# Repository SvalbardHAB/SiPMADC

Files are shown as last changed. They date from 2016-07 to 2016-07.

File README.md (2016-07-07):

# Existing SiPM ADC board

This board contains two dual-channel 10 bit 65MSPS MAX1182 ADCs; kindly provided by Maxim as free samples. There is also a MachXO2
CPLD for data processing, interfacing over SPI with a microcontroller. It is designed to obtain more  quantitative 
data from the SiPM and scintillator detector than the previous comparator board; at the expense of only using four of the 16 channels.

The board also contains the SiPM bias supply, consisting of a -34V inverting buck-boost converter and an op-amp to output the exact
voltage. This, along with the midpoint voltage - note this is not how the board is designed; during assembly a wire connecting 
Vmid to one of the DAC channels was added and U1 was not populated - is set by a TI DAC7564 allowing precise closed-case software adjustment.

At present the board has been assembled and tested. Unfortunately one of the ADC channels is not functioning correctly and
needs to be investigated further; this is suspected to be an assembly issue.

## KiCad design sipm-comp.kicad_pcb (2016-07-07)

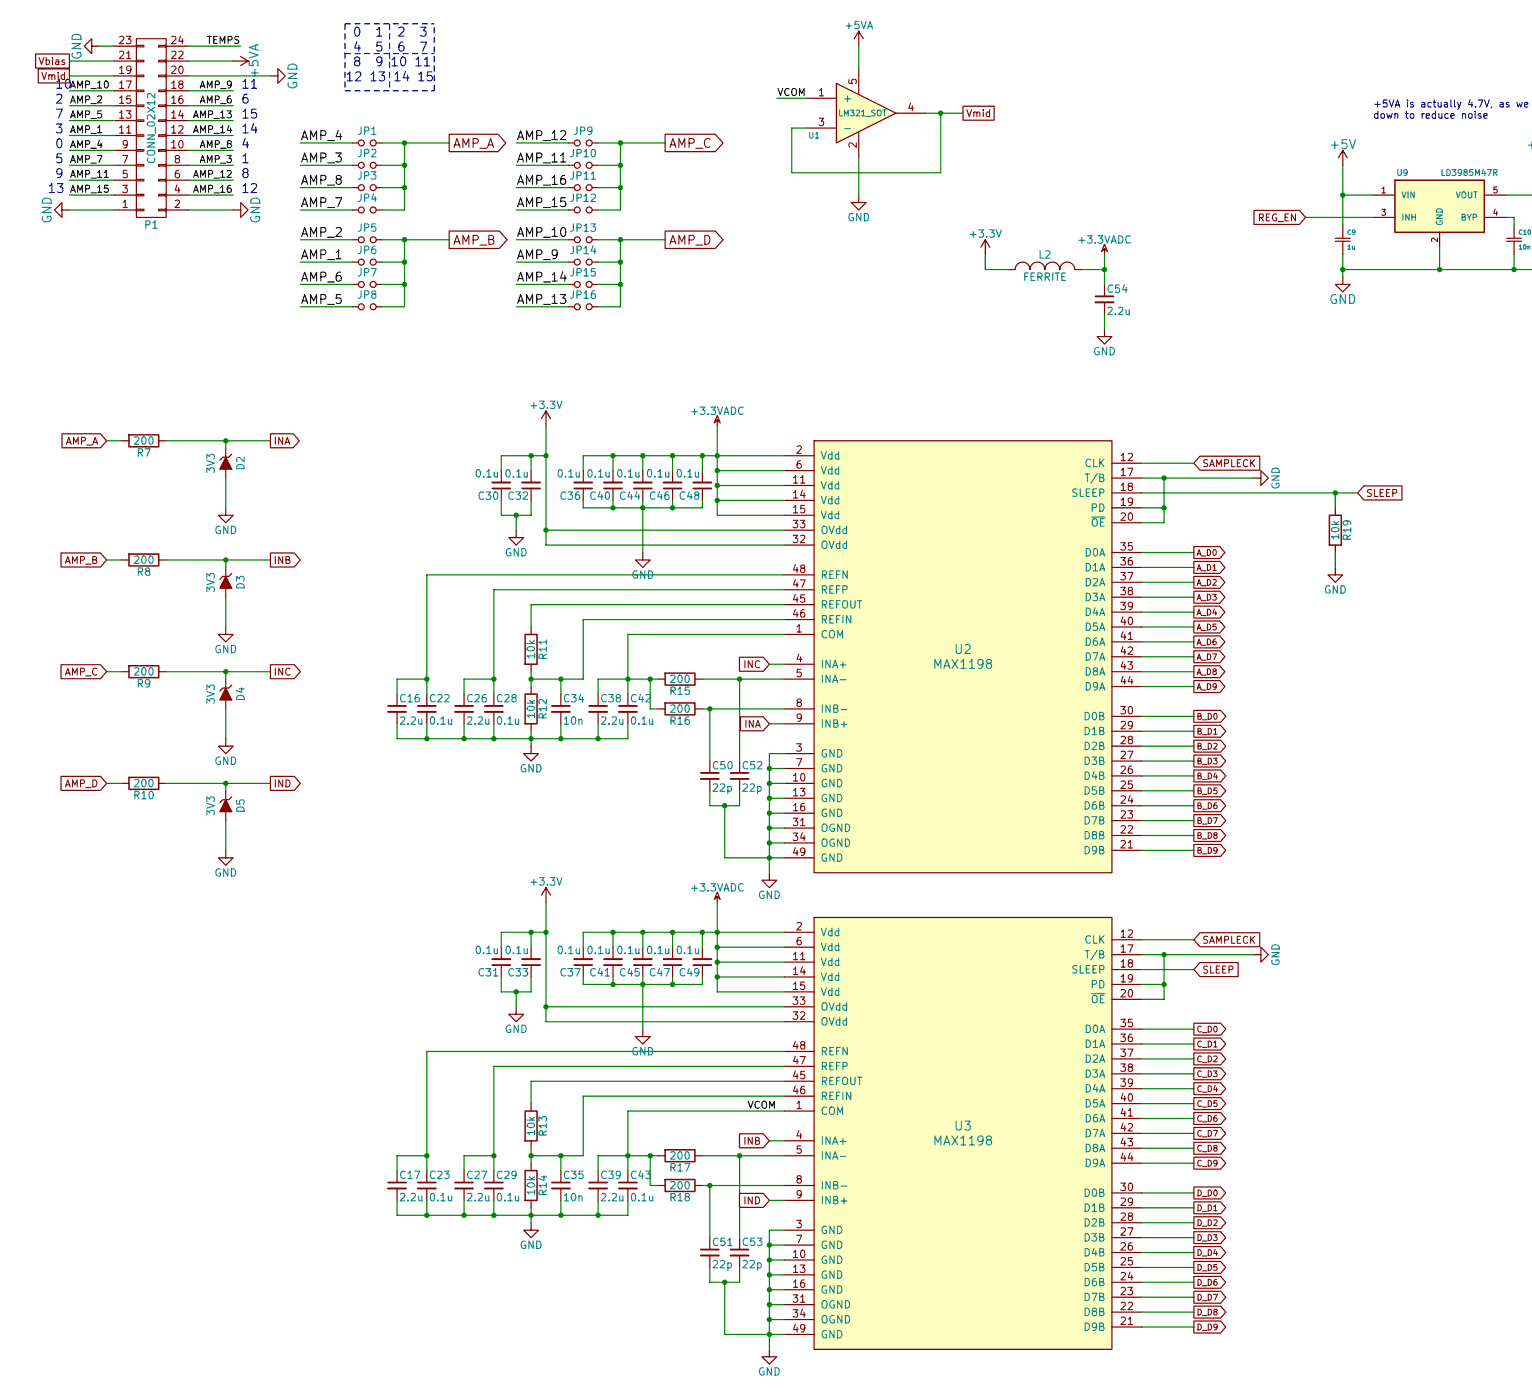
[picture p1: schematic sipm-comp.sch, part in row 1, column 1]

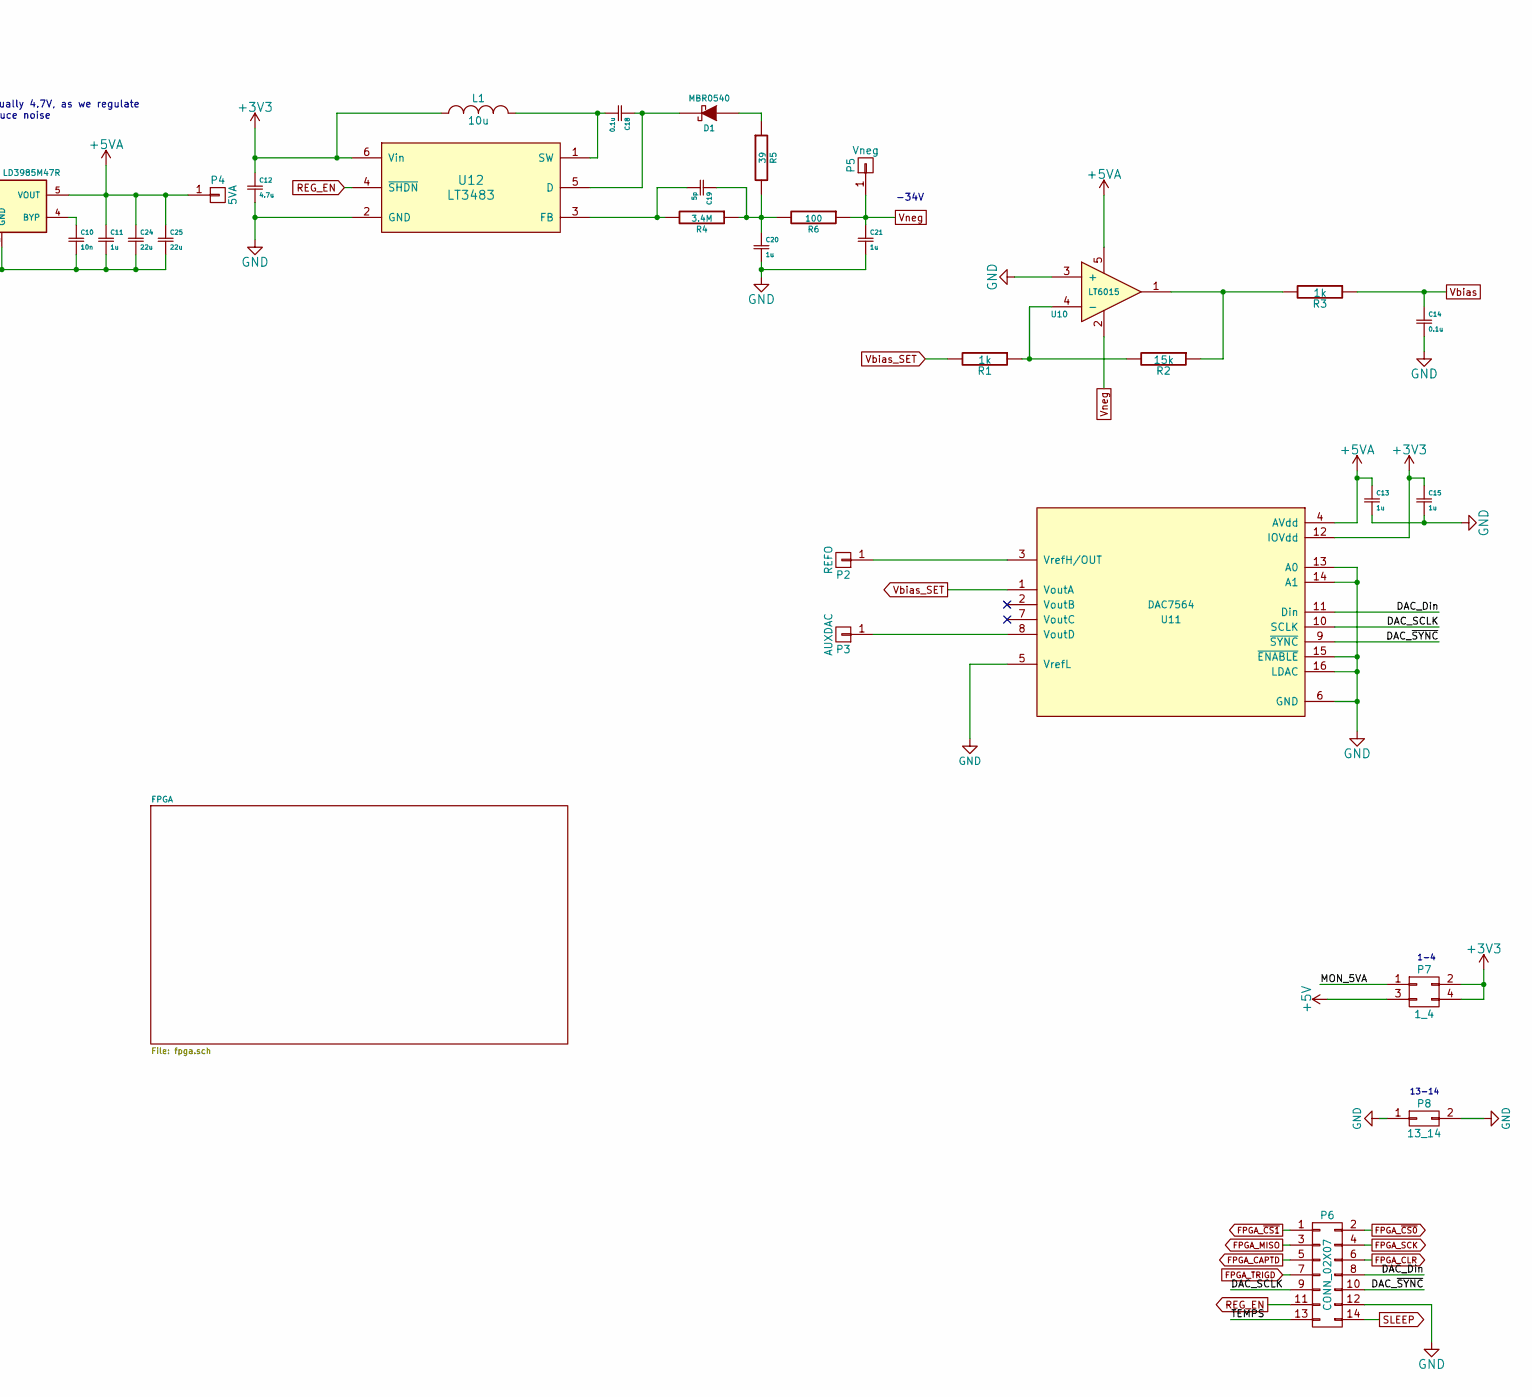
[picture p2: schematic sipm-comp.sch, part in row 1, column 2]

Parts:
C9, C11, C13, C15: 1u; C_0603
C10, C34, C35: 10n; C_0402
C12: 4.7u; C_0805
C14, C18: 0.1u; C_0805
C16, C17, C26, C27, C38, C39, C54: 2.2u; C_0603
C19: 5p; C_0402
C20, C21: 1u; C_1206
C22, C23: 0.1u; C_0603
C24, C25: 22u; C_1206
C28, C29, C30, C31, C32, C33, C36, C37, C40, C41, C42, C43, C44, C45, C46, C47, C48, C49: 0.1u; C_0402
C50, C51, C52, C53: 22p; C_0402
D1: MBR0540; SOD-123
D2, D3, D4, D5: 3V3; SOD-123
JP1, JP2, JP3, JP4, JP5, JP6, JP7, JP8, JP9, JP10, JP11, JP12, JP13, JP14, JP15, JP16: Jumper_NO_Small; MINI_JMPR
L1: 10u; Neosid_Inductor_SM-NE45_SMD1812
L2: FERRITE; R_0805
P1: CONN_02X12; Pin_Header_Angled_2x12
P2: REFO; Measurement_Point_Round-SMD-Pad_Small
P3: AUXDAC; Measurement_Point_Round-SMD-Pad_Small
P4: 5VA; Measurement_Point_Round-SMD-Pad_Small
P5: Vneg; Measurement_Point_Round-SMD-Pad_Small
P6: CONN_02X07; Pin_Header_Straight_2x07
P7: 1_4; Pin_Header_Straight_2x02
P8: 13_14; Pin_Header_Straight_2x01
R1, R3: 1k; R_0402
R2: 15k; R_0402
R4: 3.4M; R_0402
R5: 39; R_0402
R6: 100; R_0402
R7, R8, R9, R10, R15, R16, R17, R18: 200; R_0402
R11, R12, R13, R14, R19: 10k; R_0402
U1: LM321_SOT; SOT-23-5
U2, U3: MAX1198; LQFP-48_7x7mm_EP4x4
U9: LD3985M47R; SOT-23-5
U10: LT6015; SOT-23-5
U11: DAC7564; TSSOP-16_4.4x5mm_Pitch0.65mm
U12: LT3483; SOT-23-6

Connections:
+3.3VADC: C36.2, C37.2, C40.2, C41.2, C44.2, C45.2, C46.2, C47.2, C48.2, C49.2, C54.1, L2.2, U2.2 (Vdd), U2.6 (Vdd), U2.11 (Vdd), U2.14 (Vdd), U2.15 (Vdd), U3.2 (Vdd), U3.6 (Vdd), U3.11 (Vdd), U3.14 (Vdd), U3.15 (Vdd)
+5V: C9.1, P7.3, U9.1 (VIN)
+5VA: C11.1, C13.1, C24.1, C25.1, P1.22, P4.1, U1.5, U9.5 (VOUT), U10.5, U11.4 (AVdd)
/AMP_1: JP6.1, P1.11
/AMP_2: JP5.1, P1.15
/AMP_3: JP2.1, P1.8
/AMP_4: JP1.1, P1.9
/AMP_5: JP8.1, P1.13
/AMP_6: JP7.1, P1.16
/AMP_7: JP4.1, P1.7
/AMP_8: JP3.1, P1.10
/AMP_9: JP14.1, P1.18
/AMP_10: JP13.1, P1.17
/AMP_11: JP10.1, P1.5
/AMP_12: JP9.1, P1.6
/AMP_13: JP16.1, P1.14
/AMP_14: JP15.1, P1.12
/AMP_15: JP12.1, P1.3
/AMP_16: JP11.1, P1.4
/DAC_Din: P6.8, U11.11 (Din)
/DAC_SCLK: P6.9, U11.10 (SCLK)
/DAC_~SYNC: P6.10, U11.9 (~SYNC)
/MON_5VA: P7.1
/TEMPS: P1.24, P6.13
/VCOM: C39.1, C43.1, R17.2, R18.2, U1.1 (+), U3.1 (COM)
AMP_A: JP1.2, JP2.2, JP3.2, JP4.2, R7.2
AMP_B: JP5.2, JP6.2, JP7.2, JP8.2, R8.2
AMP_C: JP9.2, JP10.2, JP11.2, JP12.2, R9.2
AMP_D: JP13.2, JP14.2, JP15.2, JP16.2, R10.2
A_D0: U2.35 (D0A); also elsewhere on the board
A_D1: U2.36 (D1A); also elsewhere on the board
A_D2: U2.37 (D2A); also elsewhere on the board
A_D3: U2.38 (D3A); also elsewhere on the board
A_D4: U2.39 (D4A); also elsewhere on the board
A_D5: U2.40 (D5A); also elsewhere on the board
A_D6: U2.41 (D6A); also elsewhere on the board
A_D7: U2.42 (D7A); also elsewhere on the board
A_D8: U2.43 (D8A); also elsewhere on the board
A_D9: U2.44 (D9A); also elsewhere on the board
B_D0: U2.30 (D0B); also elsewhere on the board
B_D1: U2.29 (D1B); also elsewhere on the board
B_D2: U2.28 (D2B); also elsewhere on the board
B_D3: U2.27 (D3B); also elsewhere on the board
B_D4: U2.26 (D4B); also elsewhere on the board
B_D5: U2.25 (D5B); also elsewhere on the board
B_D6: U2.24 (D6B); also elsewhere on the board
B_D7: U2.23 (D7B); also elsewhere on the board
B_D8: U2.22 (D8B); also elsewhere on the board
B_D9: U2.21 (D9B); also elsewhere on the board
C_D0: U3.35 (D0A); also elsewhere on the board
C_D1: U3.36 (D1A); also elsewhere on the board
C_D2: U3.37 (D2A); also elsewhere on the board
C_D3: U3.38 (D3A); also elsewhere on the board
C_D4: U3.39 (D4A); also elsewhere on the board
C_D5: U3.40 (D5A); also elsewhere on the board
C_D6: U3.41 (D6A); also elsewhere on the board
C_D7: U3.42 (D7A); also elsewhere on the board
C_D8: U3.43 (D8A); also elsewhere on the board
C_D9: U3.44 (D9A); also elsewhere on the board
D_D0: U3.30 (D0B); also elsewhere on the board
D_D1: U3.29 (D1B); also elsewhere on the board
D_D2: U3.28 (D2B); also elsewhere on the board
D_D3: U3.27 (D3B); also elsewhere on the board
D_D4: U3.26 (D4B); also elsewhere on the board
D_D5: U3.25 (D5B); also elsewhere on the board
D_D6: U3.24 (D6B); also elsewhere on the board
D_D7: U3.23 (D7B); also elsewhere on the board
D_D8: U3.22 (D8B); also elsewhere on the board
D_D9: U3.21 (D9B); also elsewhere on the board
FPGA_CAPTD: P6.5; also elsewhere on the board
FPGA_CLR: P6.6; also elsewhere on the board
FPGA_MISO: P6.3; also elsewhere on the board
FPGA_SCK: P6.4; also elsewhere on the board
FPGA_TRIGD: P6.7; also elsewhere on the board
FPGA_~CS0: P6.2; also elsewhere on the board
FPGA_~CS1: P6.1; also elsewhere on the board
GND: C9.2, C10.2, C11.2, C12.2, C13.2, C14.2, C15.2, C16.2, C17.2, C20.2, C21.2, C22.2, C23.2, C24.2, C25.2, C26.2, C27.2, C28.2, C29.2, C30.1, C31.1, C32.1, C33.1, C34.2, C35.2, C36.1, C37.1, C38.2, C39.2, C40.1, C41.1, C42.2, C43.2, C44.1, C45.1, C46.1, C47.1, C48.1, C49.1, C50.2, C51.2, C52.2, C53.2, C54.2, D2.2 (A), D3.2 (A), D4.2 (A), D5.2 (A), P1.1, P1.2, P1.20, P1.23, P6.12, P8.1, P8.2, R12.2, R14.2, R19.2, U1.2, U2.3 (GND), U2.7 (GND), U2.10 (GND), U2.13 (GND), U2.16 (GND), U2.17 (T/B), U2.19 (PD), U2.20 (~OE), U2.31 (OGND), U2.34 (OGND), U2.49 (GND), U3.3 (GND), U3.7 (GND), U3.10 (GND), U3.13 (GND), U3.16 (GND), U3.17 (T/B), U3.19 (PD), U3.20 (~OE), U3.31 (OGND), U3.34 (OGND), U3.49 (GND), U9.2 (GND), U10.3 (+), U11.5 (VrefL), U11.6 (GND), U11.13 (A0), U11.14 (A1), U11.15 (~ENABLE), U11.16 (LDAC), U12.2 (GND); also elsewhere on the board
INA: D2.1 (K), R7.1, U2.9 (INB+)
INB: D3.1 (K), R8.1, U3.4 (INA+)
INC: D4.1 (K), R9.1, U2.4 (INA+)
IND: D5.1 (K), R10.1, U3.9 (INB+)
unnamed: C10.1, U9.4 (BYP)
unnamed: C16.1, C22.1, U2.48 (REFN)
unnamed: C17.1, C23.1, U3.48 (REFN)
unnamed: C18.1, D1.2 (K), U12.5 (D)
unnamed: C18.2, L1.2, U12.1 (SW)
unnamed: C19.1, C20.1, R4.1, R5.2, R6.2
unnamed: C19.2, R4.2, U12.3 (FB)
unnamed: C26.1, C28.1, U2.47 (REFP)
unnamed: C27.1, C29.1, U3.47 (REFP)
unnamed: C34.1, R11.2, R12.1, U2.46 (REFIN)
unnamed: C35.1, R13.2, R14.1, U3.46 (REFIN)
unnamed: C38.1, C42.1, R15.2, R16.2, U2.1 (COM)
unnamed: C50.1, R16.1, U2.8 (INB-)
unnamed: C51.1, R18.1, U3.8 (INB-)
unnamed: C52.1, R15.1, U2.5 (INA-)
unnamed: C53.1, R17.1, U3.5 (INA-)
unnamed: D1.1 (A), R5.1
unnamed: P2.1, U11.3 (VrefH/OUT)
unnamed: P3.1, U11.8 (VoutD)
unnamed: R1.1, R2.2, U10.4 (-)
unnamed: R2.1, R3.2, U10.1
unnamed: R11.1, U2.45 (REFOUT)
unnamed: R13.1, U3.45 (REFOUT)
REG_EN: P6.11, U9.3 (INH), U12.4 (~SHDN)
SAMPLECK: U2.12 (CLK), U3.12 (CLK); also elsewhere on the board
SLEEP: P6.14, R19.1, U2.18 (SLEEP), U3.18 (SLEEP)
Vbias: C14.1, P1.21, R3.1
Vbias_SET: R1.2, U11.1 (VoutA)
Vmid: P1.19, U1.3 (-), U1.4
Vneg: C21.1, P5.1, R6.1, U10.2

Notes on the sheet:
+5VA is actually 4.7V, as we regulate down to reduce noise
-34V
1-4
13-14
0 1 2 3
4 5 6 7
8 9 10 11
12 13 14 15

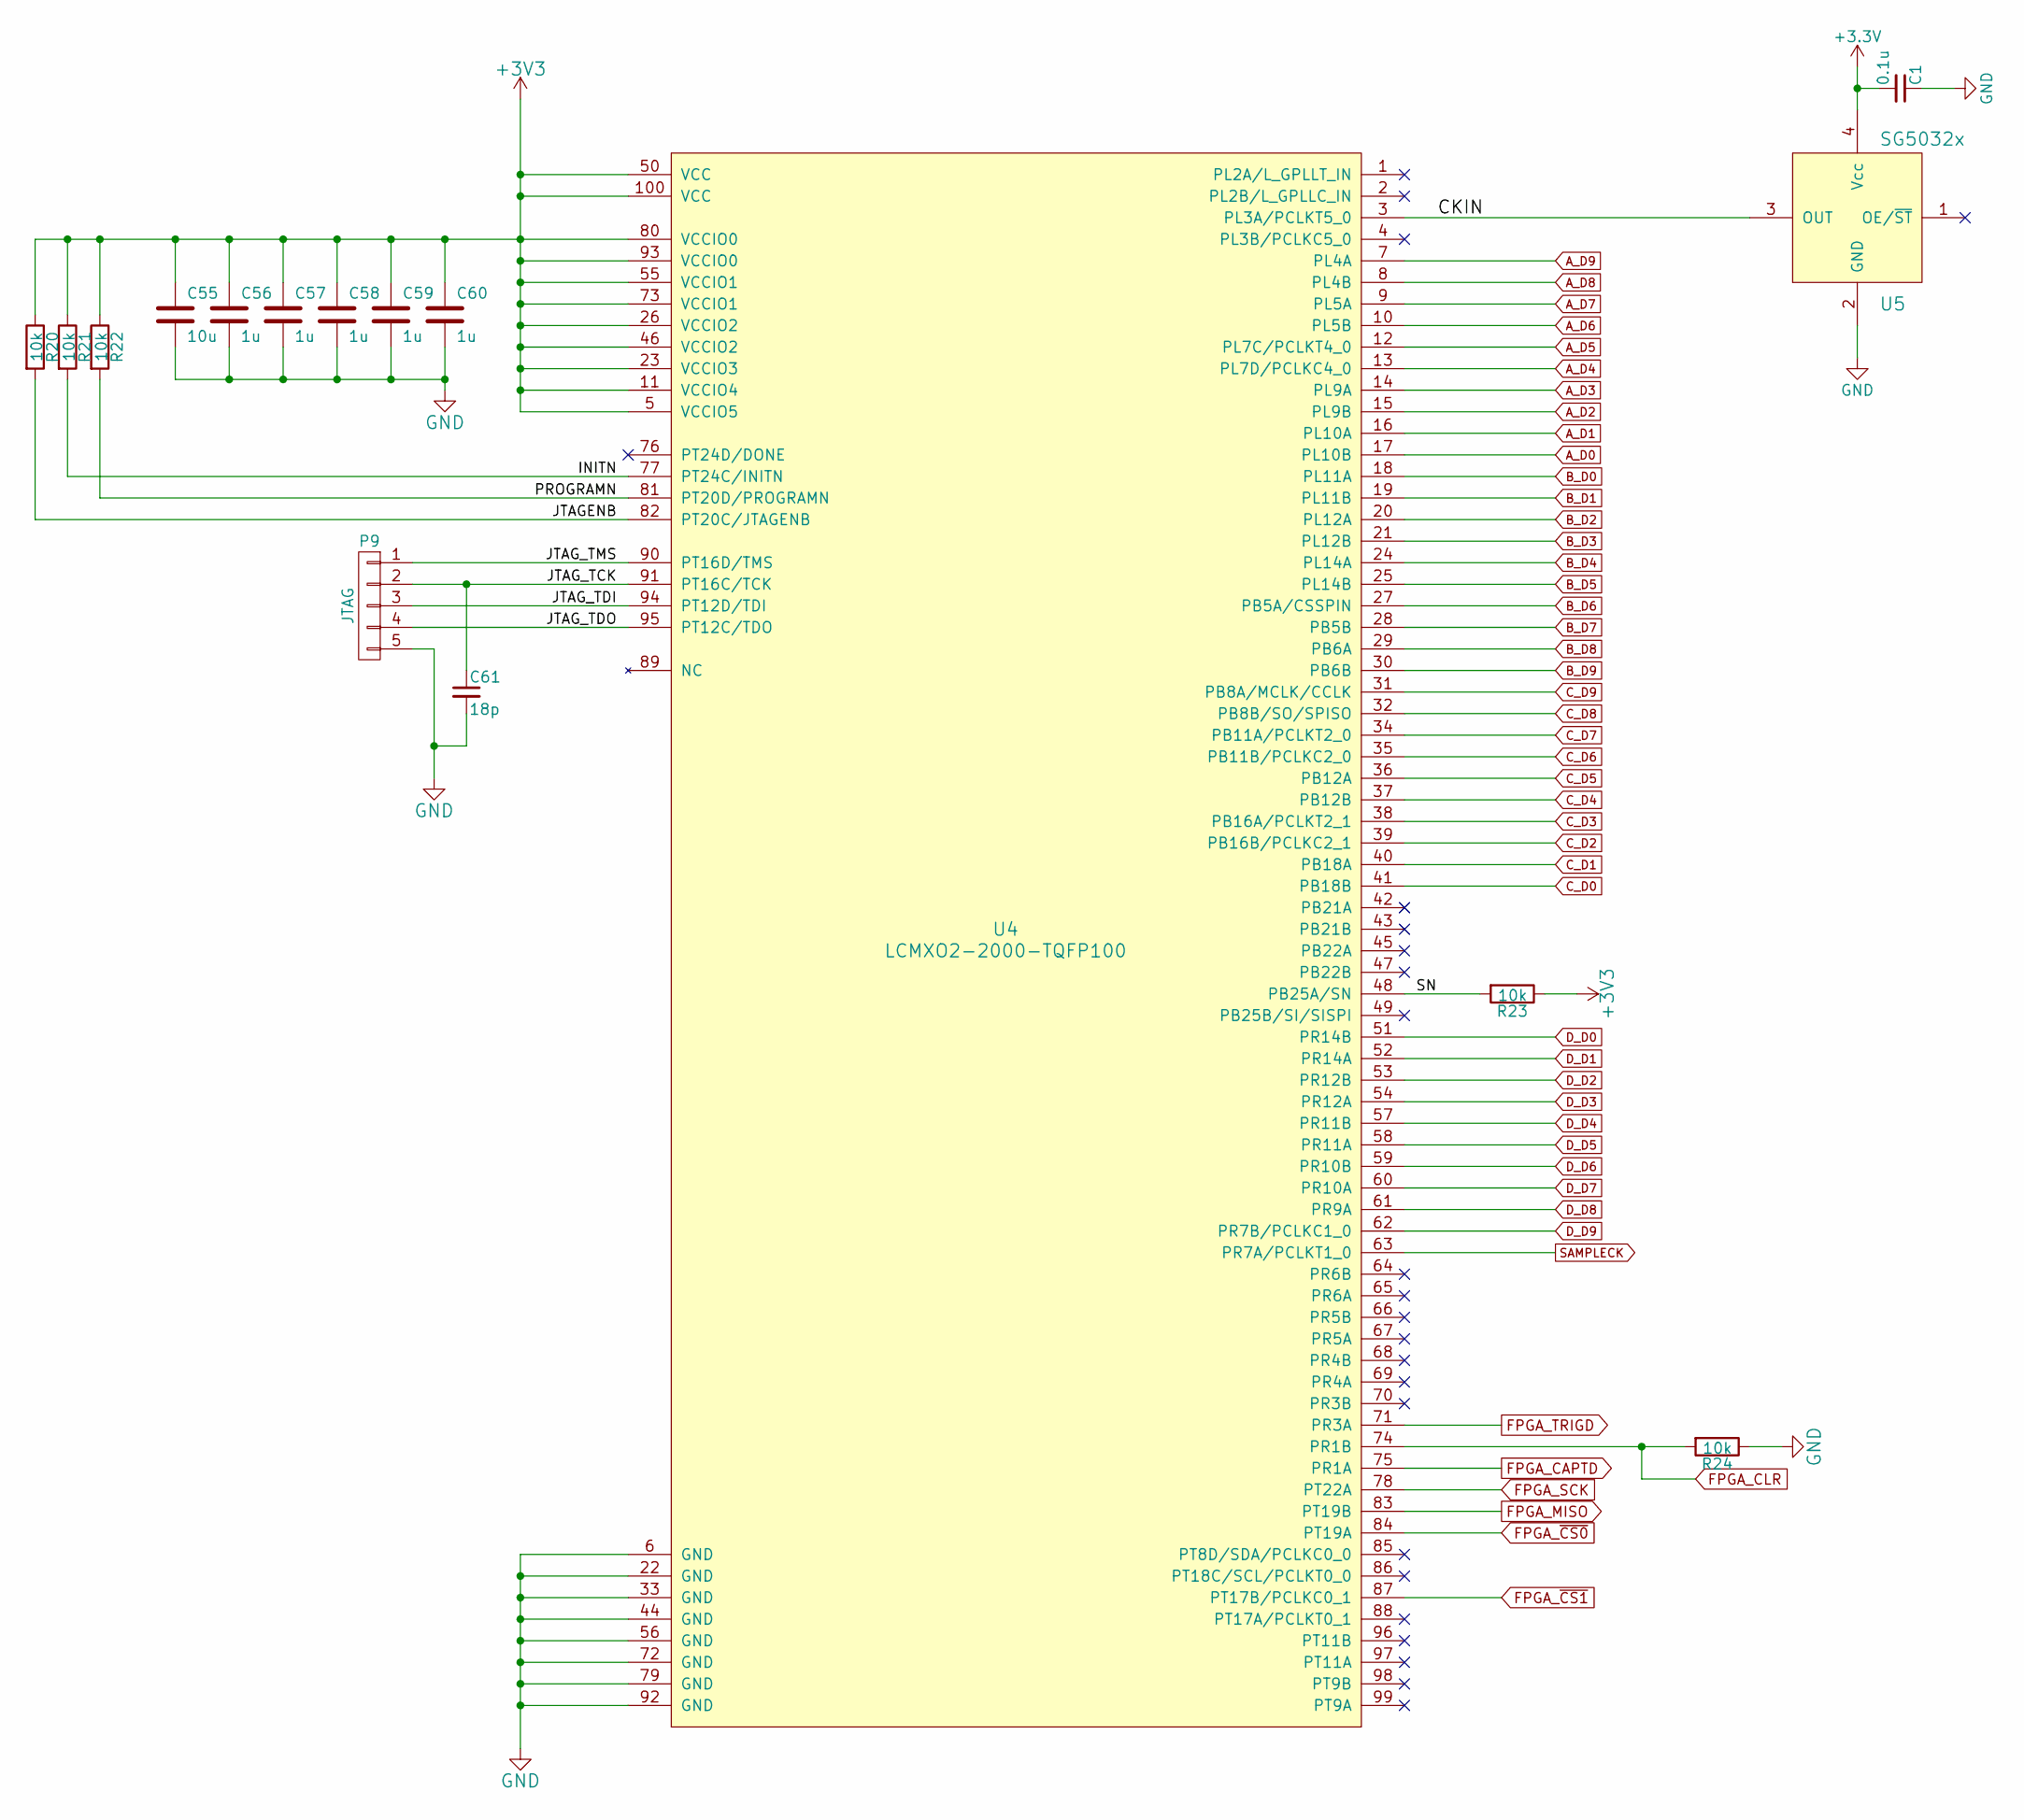
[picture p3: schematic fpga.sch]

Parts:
C1: 0.1u; C_0402
C55: 10u; C_0805
C56, C57, C58, C59, C60: 1u; C_0603
C61: 18p; C_0402
P9: JTAG; Pin_Header_Straight_1x05
R20, R21, R22, R23, R24: 10k; R_0402
U4: LCMXO2-2000-TQFP100; TQFP-100_14x14mm_Pitch0.5mm
U5: SG5032x; SG5032

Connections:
/FPGA/CKIN: U4.3 (PL3A/PCLKT5_0), U5.3 (OUT)
/FPGA/INITN: R21.2, U4.77 (PT24C/INITN)
/FPGA/JTAGENB: R20.2, U4.82 (PT20C/JTAGENB)
/FPGA/JTAG_TCK: C61.1, P9.2, U4.91 (PT16C/TCK)
/FPGA/JTAG_TDI: P9.3, U4.94 (PT12D/TDI)
/FPGA/JTAG_TDO: P9.4, U4.95 (PT12C/TDO)
/FPGA/JTAG_TMS: P9.1, U4.90 (PT16D/TMS)
/FPGA/PROGRAMN: R22.2, U4.81 (PT20D/PROGRAMN)
/FPGA/SN: R23.2, U4.48 (PB25A/SN)
A_D0: U4.17 (PL10B); also elsewhere on the board
A_D1: U4.16 (PL10A); also elsewhere on the board
A_D2: U4.15 (PL9B); also elsewhere on the board
A_D3: U4.14 (PL9A); also elsewhere on the board
A_D4: U4.13 (PL7D/PCLKC4_0); also elsewhere on the board
A_D5: U4.12 (PL7C/PCLKT4_0); also elsewhere on the board
A_D6: U4.10 (PL5B); also elsewhere on the board
A_D7: U4.9 (PL5A); also elsewhere on the board
A_D8: U4.8 (PL4B); also elsewhere on the board
A_D9: U4.7 (PL4A); also elsewhere on the board
B_D0: U4.18 (PL11A); also elsewhere on the board
B_D1: U4.19 (PL11B); also elsewhere on the board
B_D2: U4.20 (PL12A); also elsewhere on the board
B_D3: U4.21 (PL12B); also elsewhere on the board
B_D4: U4.24 (PL14A); also elsewhere on the board
B_D5: U4.25 (PL14B); also elsewhere on the board
B_D6: U4.27 (PB5A/CSSPIN); also elsewhere on the board
B_D7: U4.28 (PB5B); also elsewhere on the board
B_D8: U4.29 (PB6A); also elsewhere on the board
B_D9: U4.30 (PB6B); also elsewhere on the board
C_D0: U4.41 (PB18B); also elsewhere on the board
C_D1: U4.40 (PB18A); also elsewhere on the board
C_D2: U4.39 (PB16B/PCLKC2_1); also elsewhere on the board
C_D3: U4.38 (PB16A/PCLKT2_1); also elsewhere on the board
C_D4: U4.37 (PB12B); also elsewhere on the board
C_D5: U4.36 (PB12A); also elsewhere on the board
C_D6: U4.35 (PB11B/PCLKC2_0); also elsewhere on the board
C_D7: U4.34 (PB11A/PCLKT2_0); also elsewhere on the board
C_D8: U4.32 (PB8B/SO/SPISO); also elsewhere on the board
C_D9: U4.31 (PB8A/MCLK/CCLK); also elsewhere on the board
D_D0: U4.51 (PR14B); also elsewhere on the board
D_D1: U4.52 (PR14A); also elsewhere on the board
D_D2: U4.53 (PR12B); also elsewhere on the board
D_D3: U4.54 (PR12A); also elsewhere on the board
D_D4: U4.57 (PR11B); also elsewhere on the board
D_D5: U4.58 (PR11A); also elsewhere on the board
D_D6: U4.59 (PR10B); also elsewhere on the board
D_D7: U4.60 (PR10A); also elsewhere on the board
D_D8: U4.61 (PR9A); also elsewhere on the board
D_D9: U4.62 (PR7B/PCLKC1_0); also elsewhere on the board
FPGA_CAPTD: U4.75 (PR1A); also elsewhere on the board
FPGA_CLR: R24.2, U4.74 (PR1B); also elsewhere on the board
FPGA_MISO: U4.83 (PT19B); also elsewhere on the board
FPGA_SCK: U4.78 (PT22A); also elsewhere on the board
FPGA_TRIGD: U4.71 (PR3A); also elsewhere on the board
FPGA_~CS0: U4.84 (PT19A); also elsewhere on the board
FPGA_~CS1: U4.87 (PT17B/PCLKC0_1); also elsewhere on the board
GND: C1.1, C55.2, C56.2, C57.2, C58.2, C59.2, C60.2, C61.2, P9.5, R24.1, U4.6 (GND), U4.22 (GND), U4.33 (GND), U4.44 (GND), U4.56 (GND), U4.72 (GND), U4.79 (GND), U4.92 (GND), U5.2 (GND); also elsewhere on the board
SAMPLECK: U4.63 (PR7A/PCLKT1_0); also elsewhere on the board

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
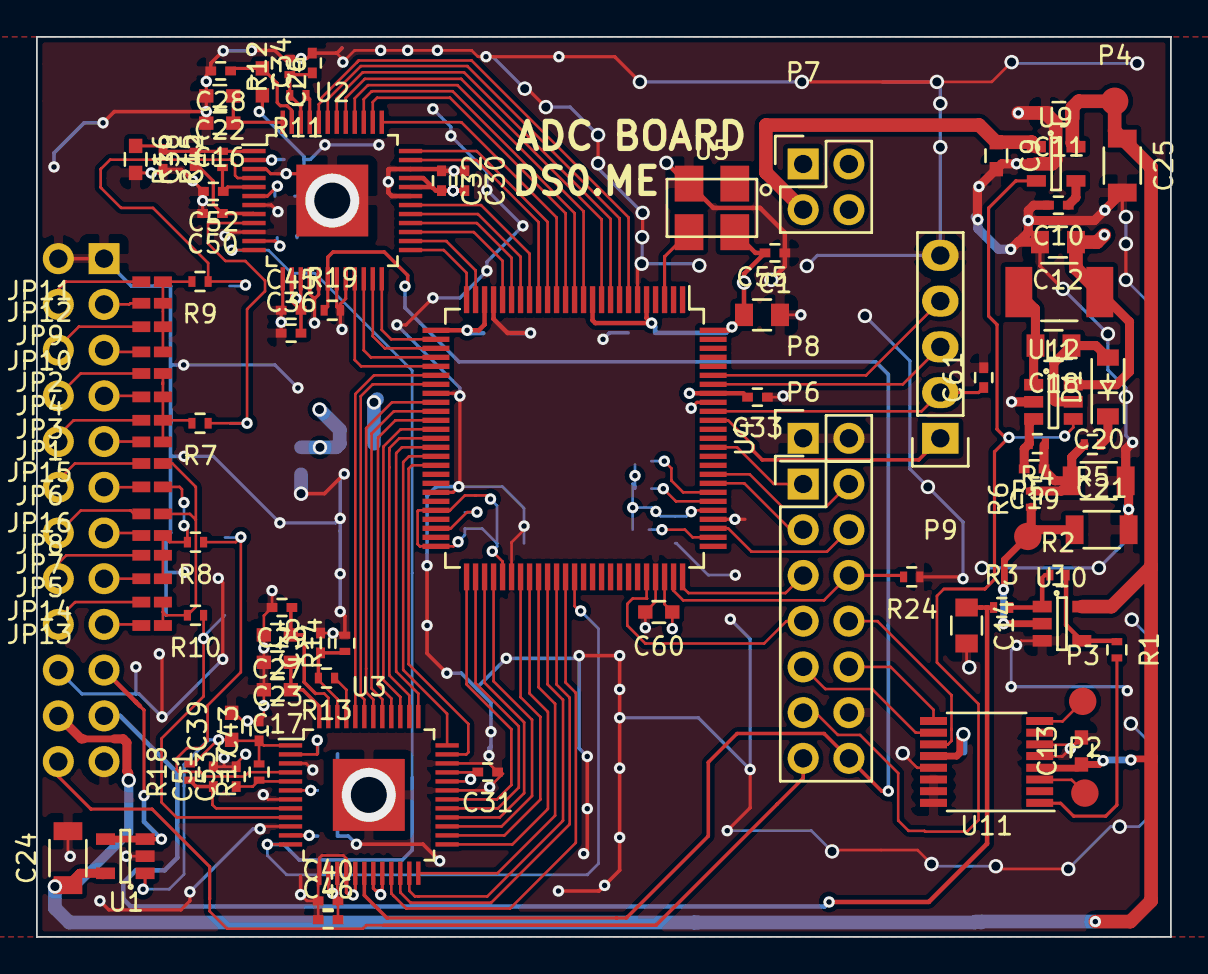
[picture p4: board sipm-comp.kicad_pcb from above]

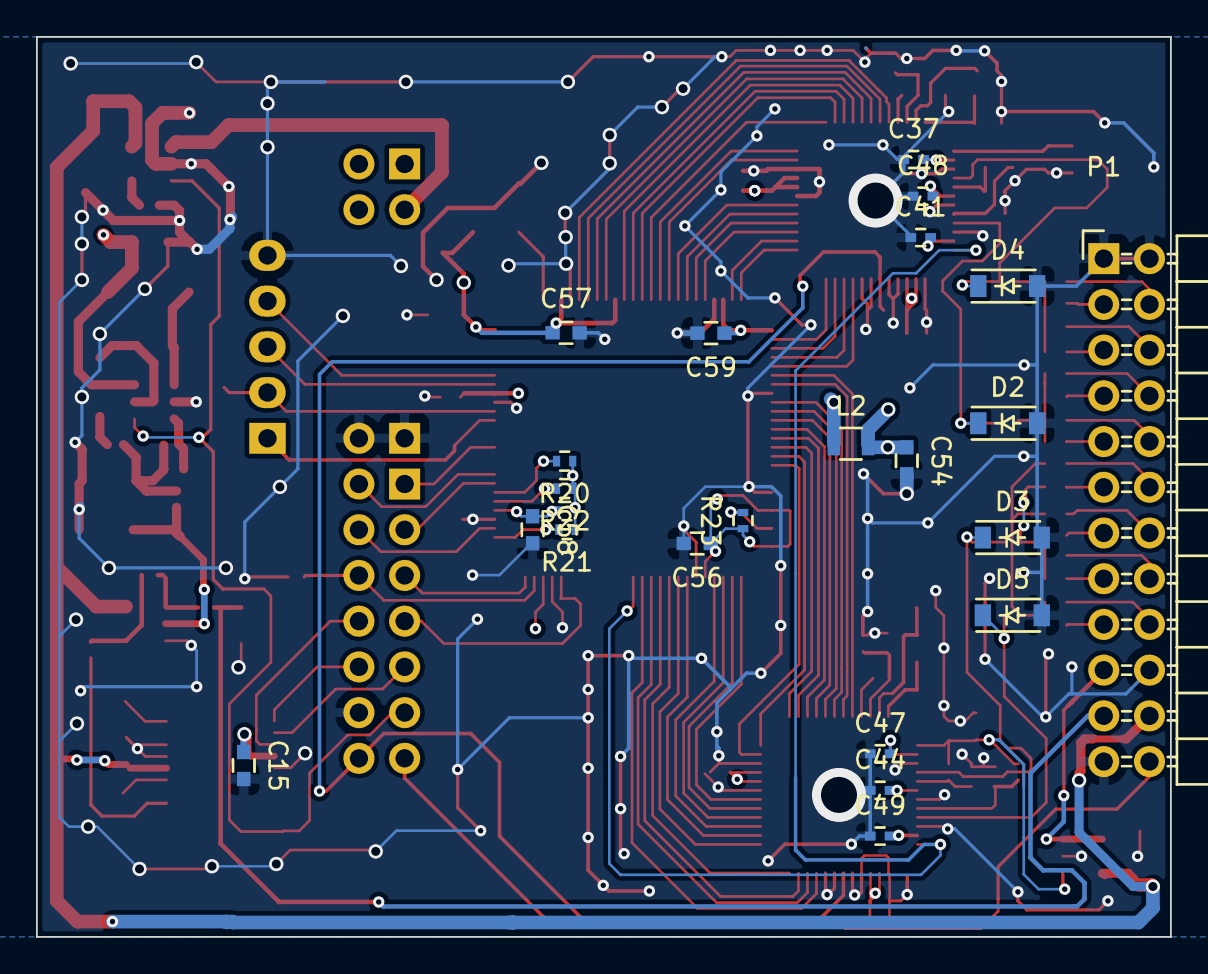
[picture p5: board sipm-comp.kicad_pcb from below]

Board: 4 copper layers, 63.0 x 50.0 mm, 119 parts (22 on the bottom side), 120 nets.
